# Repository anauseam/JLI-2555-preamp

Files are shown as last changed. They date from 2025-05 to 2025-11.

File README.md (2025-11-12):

# JLI-2555-tin-can-mic

A unprofessional "Mid"-Fi mic using a JLI 2555, meant to be housed in a tin can.

## Specs

Output voltage is designed to output a commercial level line signal via a TS connection.

All the components were designed to be purely through hole and non-obsolete, thus limiting the choices drastically.

If you would like a circuit that you can order pre made refer to the [WIP] Repo.

## Notes / Known issues

Because the potentiometer is DC biased, when the potentiometer collects dust years down the road there will be a scratching nose when turning the knob. Given that this is a literal mic housed in a tin can, I can accept this fact

Yes the entire circuit is running off of a 9v. This makes things as simple as possible, perfect for a proof of concept tin can microphone. Reasons for the unipolar supply:

- Adding a bipolar supply (two batteries) would introduce a new array of issues (e.g. uneven battery drain, size)

The biggest issue (IMO) is the OPA134 itself. Although it does have an excellent noise floor compared to standard op amps, compared a something like the OPA1642, or a proper discrete JFET, it has a noise floor of about 12.45 nV/sqrt(Hz) when considering the op amp's voltage noise and the voltage noise from the affect of the op amp's current noise and 1G resistor.

## TODO

Current the PCB is haphazardly connected, a proper layout will be completed once testing of the original circuit is done.

I will probably create a proper pcb with SMT

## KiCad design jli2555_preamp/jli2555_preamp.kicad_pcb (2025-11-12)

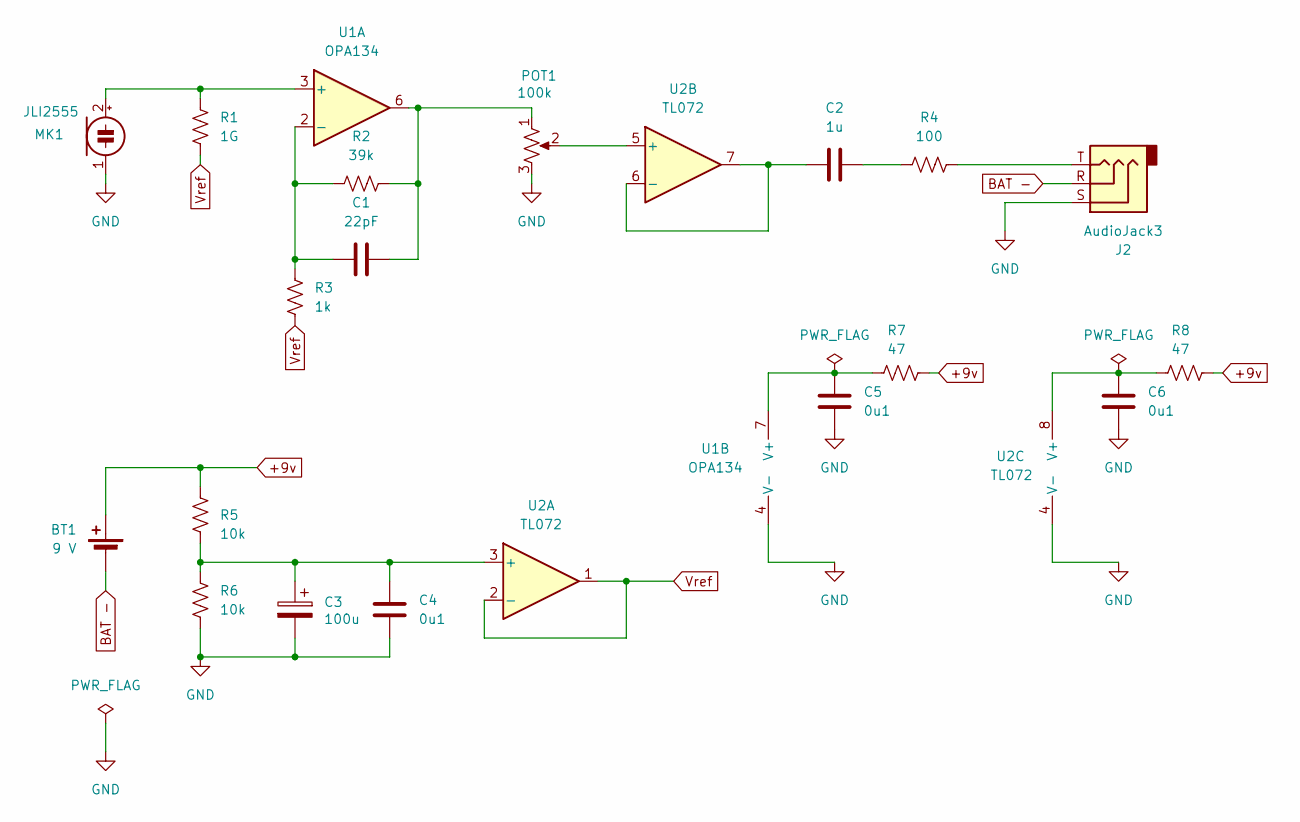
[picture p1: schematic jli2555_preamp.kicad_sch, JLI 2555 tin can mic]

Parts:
BT1: 9 V; BatteryHolder_MPD_BA9VPC_1xPP3
C1: 22pF; C_Disc_D5.0mm_W2.5mm_P2.50mm
C2: 1u; C_Rect_L7.2mm_W4.5mm_P5.00mm_FKS2_FKP2_MKS2_MKP2
C3: 100u; CP_Radial_D6.3mm_P2.50mm
C4: 0u1; C_Disc_D5.0mm_W2.5mm_P5.00mm
C5, C6: 0u1; C_Disc_D5.0mm_W2.5mm_P2.50mm
J2: AudioJack3; Jack_3.5mm_CUI_SJ1-3513N_Horizontal
MK1: JLI2555; SolderWire-0.1sqmm_1x02_P3.6mm_D0.4mm_OD1mm
POT1: 100k; Potentiometer_Alps_RK09Y11_Single_Horizontal
R1: 1G; R_Axial_DIN0207_L6.3mm_D2.5mm_P10.16mm_Horizontal
R2: 39k; R_Axial_DIN0207_L6.3mm_D2.5mm_P10.16mm_Horizontal
R3: 1k; R_Axial_DIN0207_L6.3mm_D2.5mm_P10.16mm_Horizontal
R4: 100; R_Axial_DIN0207_L6.3mm_D2.5mm_P10.16mm_Horizontal
R5, R6: 10k; R_Axial_DIN0207_L6.3mm_D2.5mm_P10.16mm_Horizontal
R7, R8: 47; R_Axial_DIN0207_L6.3mm_D2.5mm_P10.16mm_Horizontal
U1: OPA134; DIP-8_W7.62mm_Socket
U2: TL072; DIP-8_W7.62mm_Socket

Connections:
+9v: BT1.1 (+), R5.1, R7.2, R8.2
BAT -: BT1.2 (-), J2.R
GND: C3.2, C4.1, C5.1, C6.1, J2.S, MK1.1 (-), POT1.3, R6.2, U1.4 (V-), U2.4 (V-)
unnamed: C1.2, POT1.1, R2.2, U1.6
unnamed: C2.2, R4.1
unnamed: J2.T, R4.2
unnamed: MK1.2 (+), R1.1, U1.3 (+)
unnamed: C1.1, R2.1, R3.1, U1.2 (-)
unnamed: C5.2, R7.1, U1.7 (V+)
unnamed: C3.1, C4.2, R5.2, R6.1, U2.3 (+)
unnamed: POT1.2, U2.5 (+)
unnamed: C2.1, U2.6 (-), U2.7
unnamed: C6.2, R8.1, U2.8 (V+)
Vref: R1.2, R3.2, U2.1, U2.2 (-)

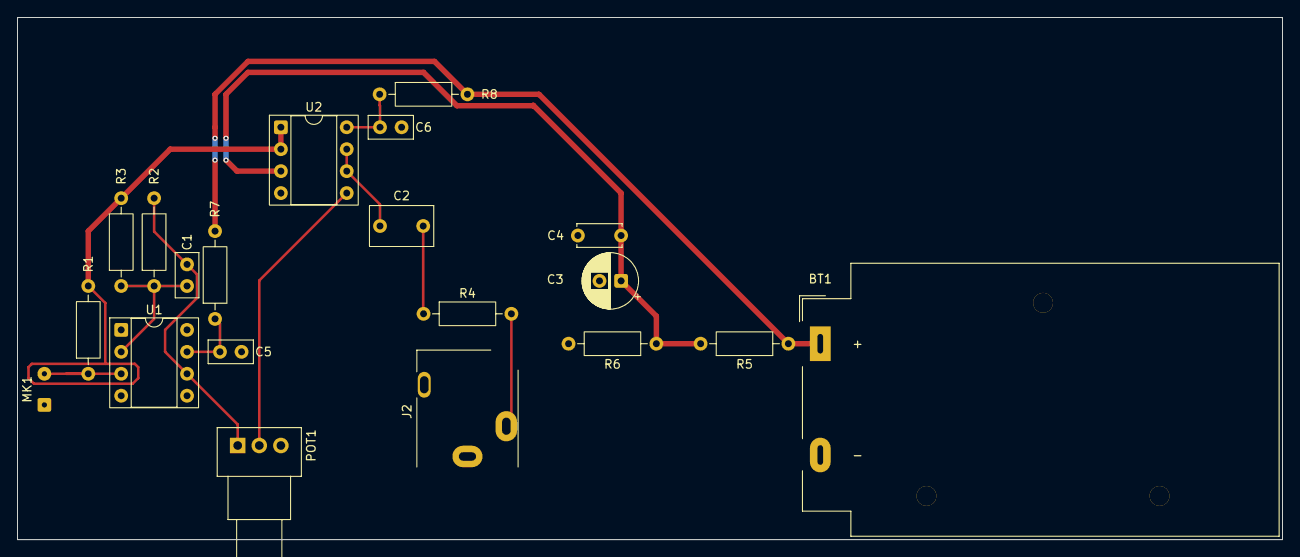
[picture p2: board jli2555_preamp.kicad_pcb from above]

Board: 2 copper layers, 146.4 x 60.4 mm, 20 parts (0 on the bottom side), 14 nets.

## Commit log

2025-05-25 Add project files
    [jli2555_preamp.kicad_pcb, jli2555_preamp.kicad_sch, jli2555_preamp_lite.kicad_pcb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]
2025-05-26 Finalize inital design of schematic
    [jli2555_preamp.kicad_sch, jli2555_preamp_lite.kicad_sch]
2025-11-07 Last version using USB power, JFET to op amp change
    [jli2555_preamp.kicad_pcb, jli2555_preamp.kicad_sch]
2025-11-12 Overhaul of the power supply, will now be a 9v supply for greater simplicity
    [jli2555_preamp.kicad_pcb, jli2555_preamp.kicad_sch]
